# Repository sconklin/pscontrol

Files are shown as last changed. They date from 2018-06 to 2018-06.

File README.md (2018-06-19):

# Control analog interface

This board is designed to connect a programmable power supply with analog control inputs and outputs to a DAQPlate, to enable network control.

# Analog conversions

### Voltage Measurement
Input -5.0V to 0V input represents 600V to 0V
Output 0 to 4.096 to DAQPlate board
Gain = -0.8192
Gain Range .714 - .896

### Current Measurement
Input 0 to 100 mV represents 0 to 1M output
Output 4.096 Volts to DAQplate
Gain = 40.96
Gain Range 38.3 - 43.3

### Voltage Control
Input from DAQplate 0 to 4.096V
Output to Powr Supply 0 to 5 volts
Gain = 1.22
Gain Range 1.098 - 1.294

### Current Limiting Control
Input from DAQplate 0 to 4.096V
Output to Power Supply 0 to 100 mV
Gain = 0.024
Gain Range .0215 - .0261

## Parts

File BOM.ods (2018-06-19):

Component | Ref | Footprint | Quantity
10 uF | C1, C11, C12 | 4x5.3 | 3
0.1 uF | C2,3,4,5,7,8,9,10,13,14,15,16 | 603 | 12
1 uF | C6 | 603 | 1
LM4030-2.5 | D1 | SOT-23-5 | 1
56K | R1, 8 | 603 | 2
40.2K | R2 | 603 | 1
1K | R3 | 603 | 1
51K | R4 | 603 | 1
42.2K | R5 | 603 | 1
38.3K | R7 | 603 | 1
910 | R9 | 603 | 1
22K | R10 | 603 | 1
510 | R14 | 603 | 1
2.32K | R15, 17, 18, 20 | 603 | 4
10K pot |  | EVM3E | 2
5K pot |  | EVM3E | 1
200 Ohm Pot |  | EVM3E | 3
LM2904 | U1, 2, 3, 4, 5 | SO-8_5.3x6.2mm | 5

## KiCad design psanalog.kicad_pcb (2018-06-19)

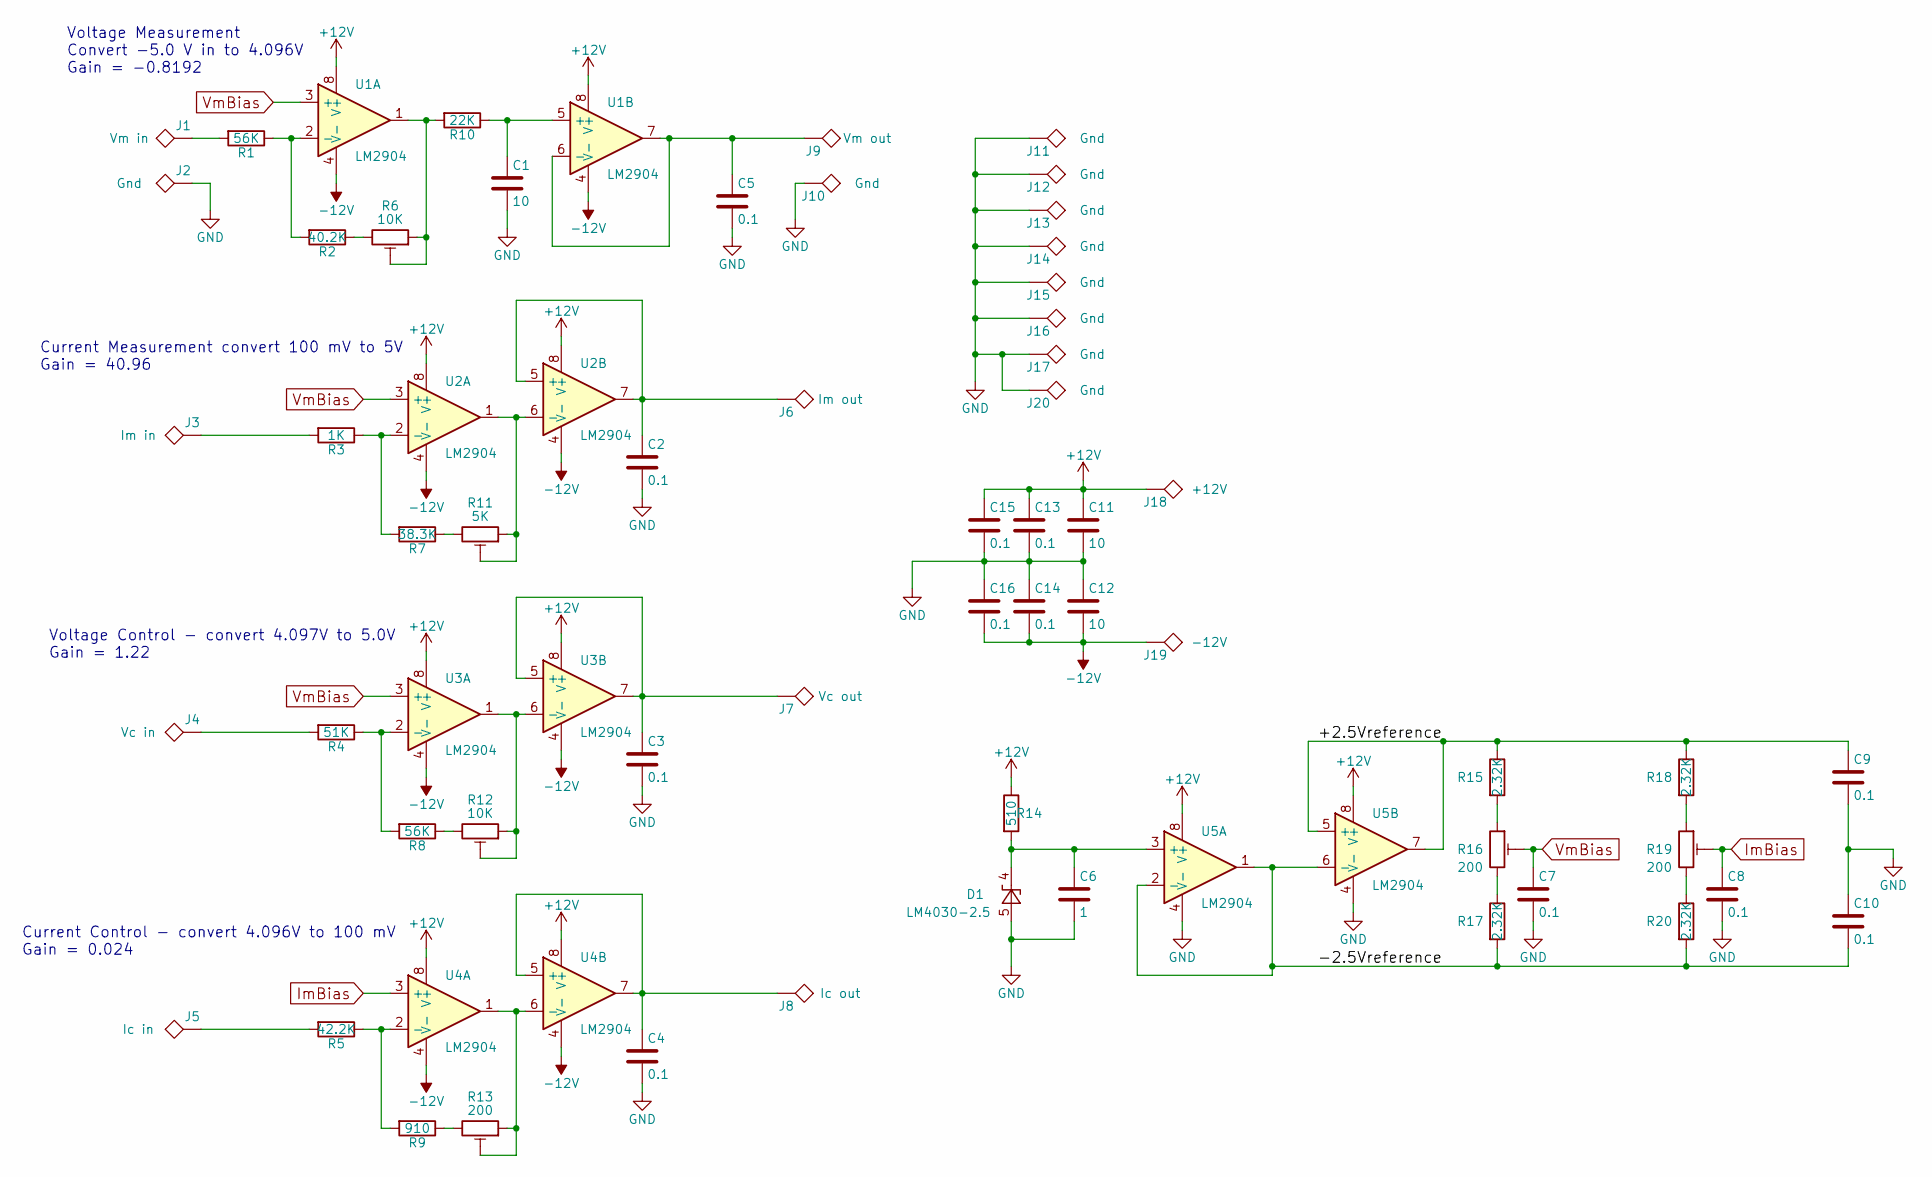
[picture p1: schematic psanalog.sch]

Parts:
C1, C11, C12: 10; CP_Elec_4x5.3
C2, C3, C4, C5, C7, C8, C9, C10, C13, C14, C15, C16: 0.1; C_0603_HandSoldering
C6: 1; C_0603_HandSoldering
D1: LM4030-2.5; SOT-23-5
J1: Vm in; SolderWirePad_single_1mmDrill
J2, J10, J11, J12, J13, J14, J15, J16, J17, J20: Gnd; SolderWirePad_single_1mmDrill
J3: Im in; SolderWirePad_single_1mmDrill
J4: Vc in; SolderWirePad_single_1mmDrill
J5: Ic in; SolderWirePad_single_1mmDrill
J6: Im out; SolderWirePad_single_1mmDrill
J7: Vc out; SolderWirePad_single_1mmDrill
J8: Ic out; SolderWirePad_single_1mmDrill
J9: Vm out; SolderWirePad_single_1mmDrill
J18: +12V; SolderWirePad_single_1mmDrill
J19: -12V; SolderWirePad_single_1mmDrill
R1, R8: 56K; R_0603_HandSoldering
R2: 40.2K; R_0603_HandSoldering
R3: 1K; R_0603_HandSoldering
R4: 51K; R_0603_HandSoldering
R5: 42.2K; R_0603_HandSoldering
R6, R12: 10K; Potentiometer_Trimmer_Bourns_3224W
R7: 38.3K; R_0603_HandSoldering
R9: 910; R_0603_HandSoldering
R10: 22K; R_0603_HandSoldering
R11: 5K; Potentiometer_Trimmer_Bourns_3224W
R13, R16, R19: 200; Potentiometer_Trimmer_Bourns_3224W
R14: 510; R_0603_HandSoldering
R15, R17, R18, R20: 2.32K; R_0603_HandSoldering
U1, U2, U3, U4, U5: LM2904; SO-8_5.3x6.2mm_Pitch1.27mm

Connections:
+12V: C11.1, C13.1, C15.1, J18.1, R14.1, U1.8 (V+), U2.8 (V+), U3.8 (V+), U4.8 (V+), U5.8 (V+)
-12V: C12.2, C14.2, C16.2, J19.1, U1.4 (V-), U2.4 (V-), U3.4 (V-), U4.4 (V-)
/+2.5Vreference: C9.1, R15.1, R18.1, U5.5 (+), U5.7
/-2.5Vreference: C10.2, R17.2, R20.2, U5.1, U5.2 (-), U5.6 (-)
GND: C1.2, C2.2, C3.2, C4.2, C5.2, C6.2, C7.2, C8.2, C9.2, C10.1, C11.2, C12.1, C13.2, C14.1, C15.2, C16.1, D1.5 (A), J2.1, J10.1, J11.1, J12.1, J13.1, J14.1, J15.1, J16.1, J17.1, J20.1, U5.4 (V-)
ImBias: C8.1, R19.2, U4.3 (+)
unnamed: C1.1, R10.1, U1.5 (+)
unnamed: C2.1, J6.1, U2.5 (+), U2.7
unnamed: C3.1, J7.1, U3.5 (+), U3.7
unnamed: C4.1, J8.1, U4.5 (+), U4.7
unnamed: C5.1, J9.1, U1.6 (-), U1.7
unnamed: C6.1, D1.4 (K), R14.2, U5.3 (+)
unnamed: J1.1, R1.2
unnamed: J3.1, R3.2
unnamed: J4.1, R4.2
unnamed: J5.1, R5.2
unnamed: R1.1, R2.2, U1.2 (-)
unnamed: R2.1, R6.3
unnamed: R3.1, R7.2, U2.2 (-)
unnamed: R4.1, R8.2, U3.2 (-)
unnamed: R5.1, R9.2, U4.2 (-)
unnamed: R6.1, R6.2, R10.2, U1.1
unnamed: R11.1, R11.2, U2.1, U2.6 (-)
unnamed: R7.1, R11.3
unnamed: R12.1, R12.2, U3.1, U3.6 (-)
unnamed: R8.1, R12.3
unnamed: R13.1, R13.2, U4.1, U4.6 (-)
unnamed: R9.1, R13.3
unnamed: R15.2, R16.1
unnamed: R16.3, R17.1
unnamed: R18.2, R19.1
unnamed: R19.3, R20.1
VmBias: C7.1, R16.2, U1.3 (+), U2.3 (+), U3.3 (+)

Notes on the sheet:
Voltage Control - convert 4.097V to 5.0V Gain = 1.22
Current Control - convert 4.096V to 100 mV Gain = 0.024
Voltage Measurement Convert -5.0 V in to 4.096V Gain = -0.8192
Current Measurement convert 100 mV to 5V Gain = 40.96

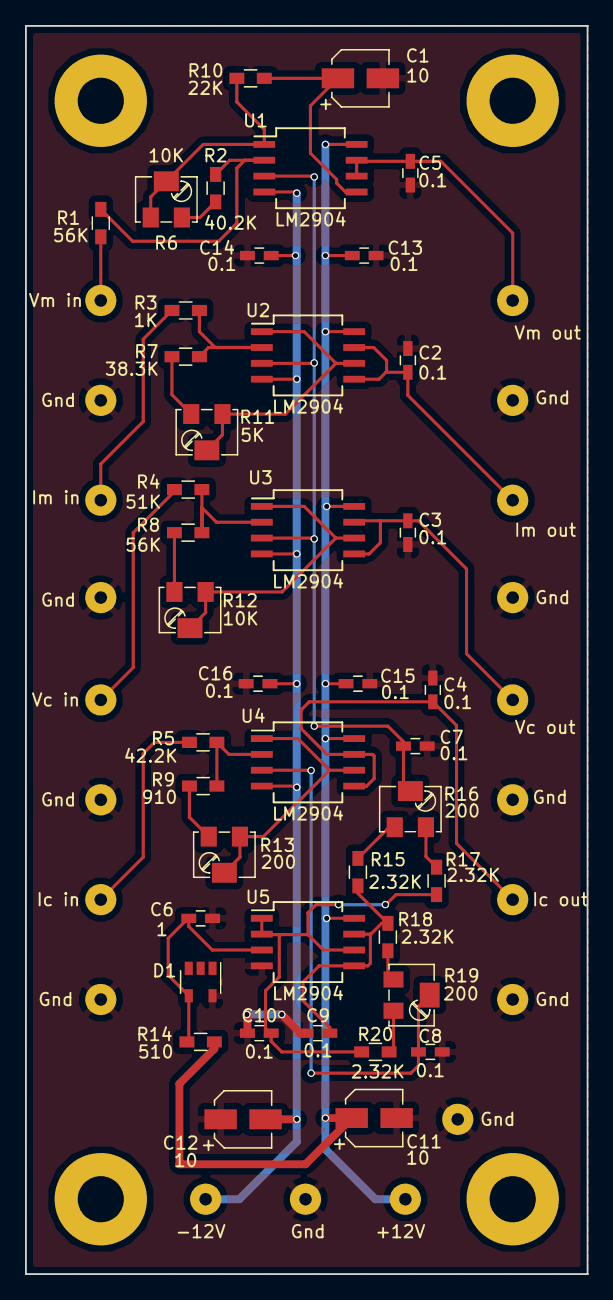
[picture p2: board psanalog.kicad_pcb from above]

Board: 2 copper layers, 45.0 x 100.0 mm, 62 parts (0 on the bottom side), 33 nets.
